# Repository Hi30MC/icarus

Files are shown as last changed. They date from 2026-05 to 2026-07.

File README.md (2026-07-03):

# icarus
Files pertaining to the development of my personal custom keyboard Icarus.

# Ergogen
The keyboard and pcb layout were generated using Ergogen locally. The config files and corresponding outputs can be found in the `ergogen` folder. There are custom footprints that generate 3d models on the footprints of all components, and these are found in `final_pcbs/components`. **The path for these are custom to my file setup, and thus will most likely not work on your machine. Please change the corresponding file paths if you wish to locally build this model.**

# KiCad
The corresponding PCB outputs from Ergogen were traced in KiCad. The final traced PCBs, along with exported STEP files are found in the `final_pcbs` folder. Currently, **the final PCBs do not have the switch and keycap models on the footprints of the switches, and there are traces which have been shown to be on fragile board sections.** Both of these changes will be updated in the near future and this notice will be removed once that happens.

# Case files
The case files were constructed in Onshape. One can view these files [here](https://cad.onshape.com/documents/795d5125a76cdfb5a48cf88b/w/a7573c951f90309017d525a7/e/47b874ca74b5b2133d47f936). There are also STEP files in this repo, in the `case_files` folder. Note that the case files provided are for the left side of the keyboard only, and the right side is simply a mirror image of the left side.

## Travel case files

As of 01 July '26, there are travel case files in the works. Please stay tuned for their release. 

# ZMK configuration.

Icarus currently runs ZMK. The configuration repository and current firmware can be found [here](https://github.com/Hi30MC/zmk-config).

# Physical build notes

This case was designed and printed for FDM, though the battery cage is a major flaw in the design. There are supports that are best printed as "normal slim" supports on Orca, for example, as these had the cleanest release. I found that it was best to print the ports/switches/etc on the case as-is, then clean up with a file, though one may find success with adding supports and removing those manually. Additionally, I reccomend placing brim ears on all corners of the faceplate/skirt print, as well as the baseplate as they tend to warp during printing. Mounting the baseplate to the PCB was done with M2.5 self-threading screws, which need washers to secure onto the board. **Print these separately, and not attached to the baseplate.** There is also a known issue with the right PCB's battery jack hitting against the Kailh hotswap bracket, which will be fixed soon™. Finally, to ensure that the keys fit into the shield, one must use flush cutters on the key-side of the shield to cut the soldering joints flush. It doesn't need to be perfectly flush, but as flush as possible is best. If any other issues arise in whoever decides to build this, please reach out!

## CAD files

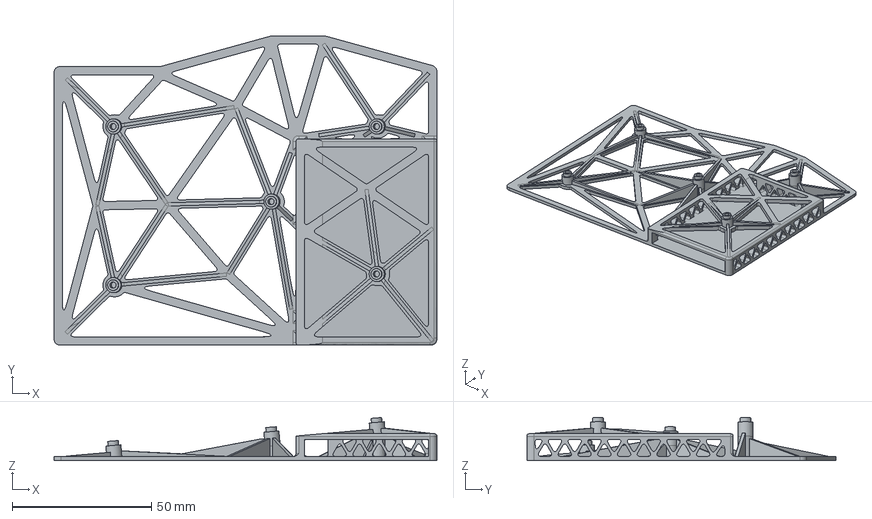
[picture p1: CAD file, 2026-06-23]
case_files/battery_cage_final.step
137.6 x 111.2 x 15.5 mm

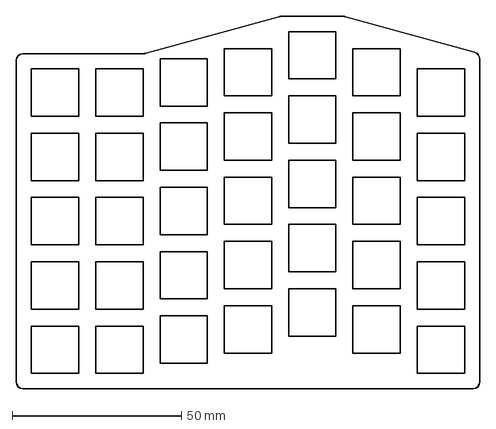
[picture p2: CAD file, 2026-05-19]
ergogen/output/outlines/leftcutout.dxf
137.0 x 110.0 mm

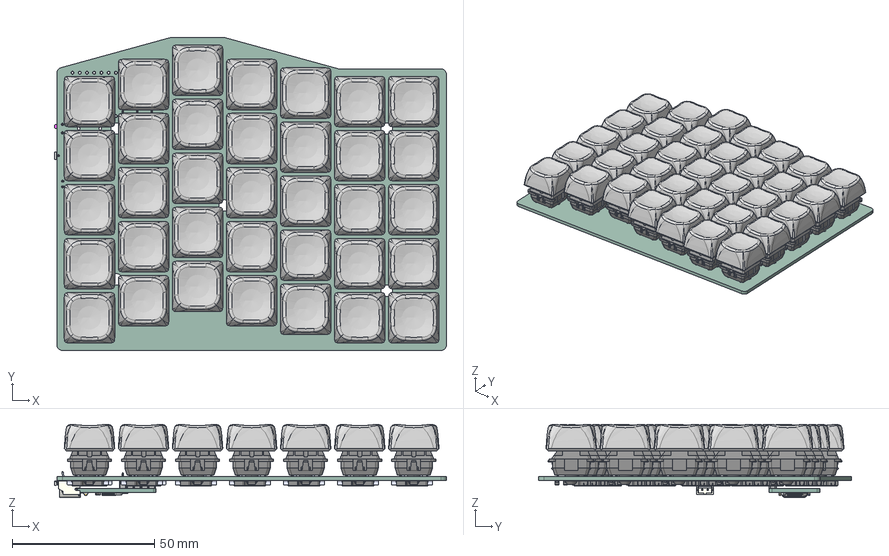
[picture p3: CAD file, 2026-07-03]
final_pcbs/3d/right_pcb.step
137.8 x 110.0 x 25.7 mm
SSSS811101
MMSZ5226B-7-F x 35
PG151101S11 x 35
MX1A-11NN x 35
1.00u (Concave) x 35
nice!nano v1.0
USB_C_Receptacle_16P_TopMnt_Horizontal_GCT_USB4105-xx-A
USB_C_Receptacle_16P_TopMnt_Horizontal_GCT_USB4105-xx-A001
USB_C_Receptacle_16P_TopMnt_Horizontal_GCT_USB4105-xx-A002
USB_C_Receptacle_16P_TopMnt_Horizontal_GCT_USB4105-xx-A003
USB_C_Receptacle_16P_TopMnt_Horizontal_GCT_USB4105-xx-A004
USB_C_Receptacle_16P_TopMnt_Horizontal_GCT_USB4105-xx-A005
USB_C_Receptacle_16P_TopMnt_Horizontal_GCT_USB4105-xx-A006
USB_C_Receptacle_16P_TopMnt_Horizontal_GCT_USB4105-xx-A007
USB_C_Receptacle_16P_TopMnt_Horizontal_GCT_USB4105-xx-A008
USB_C_Receptacle_16P_TopMnt_Horizontal_GCT_USB4105-xx-A009
USB_C_Receptacle_16P_TopMnt_Horizontal_GCT_USB4105-xx-A010
USB_C_Receptacle_16P_TopMnt_Horizontal_GCT_USB4105-xx-A011
USB_C_Receptacle_16P_TopMnt_Horizontal_GCT_USB4105-xx-A012
USB_C_Receptacle_16P_TopMnt_Horizontal_GCT_USB4105-xx-A013
USB_C_Receptacle_16P_TopMnt_Horizontal_GCT_USB4105-xx-A014
USB_C_Receptacle_16P_TopMnt_Horizontal_GCT_USB4105-xx-A015
USB_C_Receptacle_16P_TopMnt_Horizontal_GCT_USB4105-xx-A016
USB_C_Receptacle_16P_TopMnt_Horizontal_GCT_USB4105-xx-A017
USB_C_Receptacle_16P_TopMnt_Horizontal_GCT_USB4105-xx-A018
USB_C_Receptacle_16P_TopMnt_Horizontal_GCT_USB4105-xx-A019
USB_C_Receptacle_16P_TopMnt_Horizontal_GCT_USB4105-xx-A020
USB_C_Receptacle_16P_TopMnt_Horizontal_GCT_USB4105-xx-A021
USB_C_Receptacle_16P_TopMnt_Horizontal_GCT_USB4105-xx-A022
USB_C_Receptacle_16P_TopMnt_Horizontal_GCT_USB4105-xx-A023
USB_C_Receptacle_16P_TopMnt_Horizontal_GCT_USB4105-xx-A024
USB_C_Receptacle_16P_TopMnt_Horizontal_GCT_USB4105-xx-A025
USB_C_Receptacle_16P_TopMnt_Horizontal_GCT_USB4105-xx-A026
USB_C_Receptacle_16P_TopMnt_Horizontal_GCT_USB4105-xx-A027
USB_C_Receptacle_16P_TopMnt_Horizontal_GCT_USB4105-xx-A028
USB_C_Receptacle_16P_TopMnt_Horizontal_GCT_USB4105-xx-A029
USB_C_Receptacle_16P_TopMnt_Horizontal_GCT_USB4105-xx-A030
USB_C_Receptacle_16P_TopMnt_Horizontal_GCT_USB4105-xx-A031
USB_C_Receptacle_16P_TopMnt_Horizontal_GCT_USB4105-xx-A032
USB_C_Receptacle_16P_TopMnt_Horizontal_GCT_USB4105-xx-A033
USB_C_Receptacle_16P_TopMnt_Horizontal_GCT_USB4105-xx-A034
USB_C_Receptacle_16P_TopMnt_Horizontal_GCT_USB4105-xx-A035
Pin9
Pin10
Pin12
Pin11
Pin13
Pin14
Pin15
Pin16
Pin8
Pin7
Pin6
Pin5
Pin4
Pin3
Pin2
Pin1
LED_0603_1608Metric_ON v1
Capacitor v1 x 2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

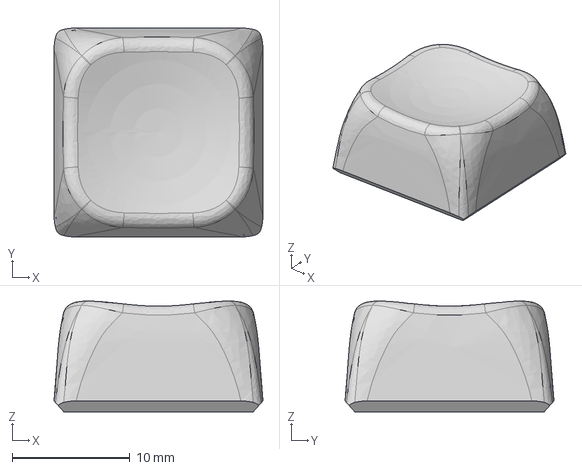
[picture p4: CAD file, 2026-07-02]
final_pcbs/components/moa_cap.step
17.8 x 17.8 x 9.43 mm

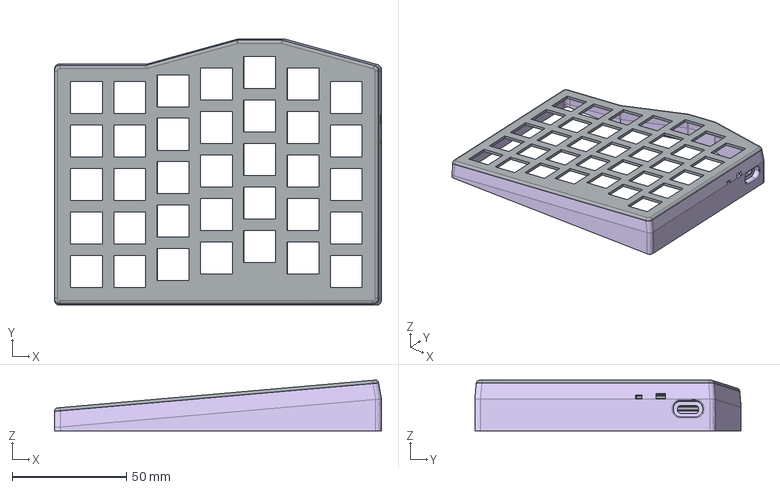
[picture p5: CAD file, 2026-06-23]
case_files/skirt_final.step
142.9 x 116.5 x 22.2 mm
faceplate
skirt

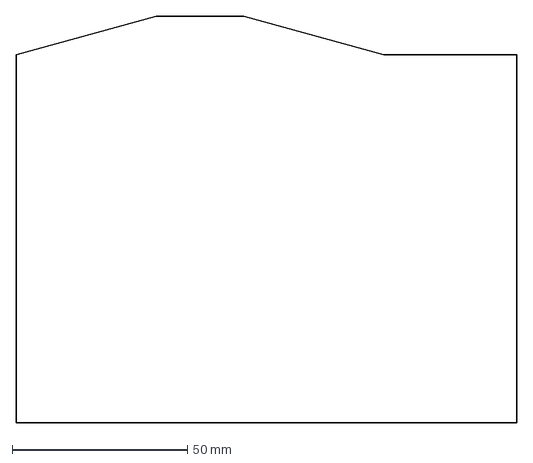
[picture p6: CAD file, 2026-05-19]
ergogen/output/outlines/rightcase.dxf
143.0 x 116.0 mm

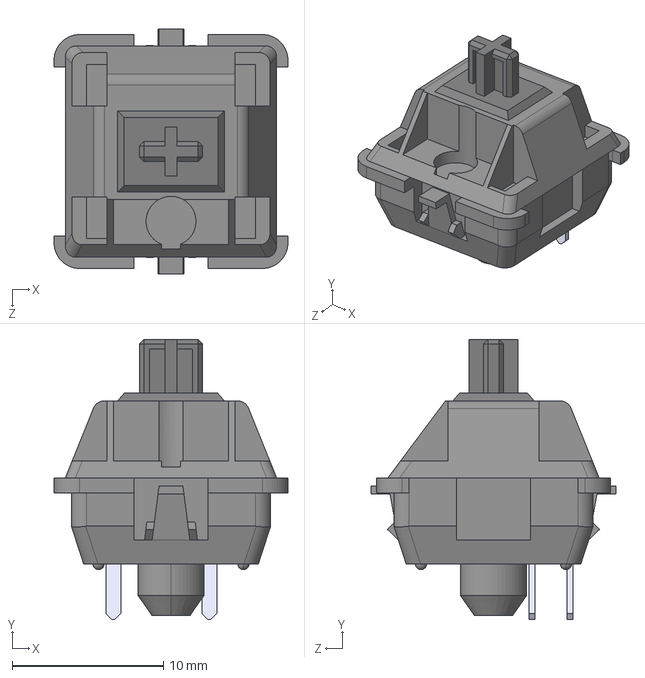
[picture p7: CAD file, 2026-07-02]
final_pcbs/components/MX1A-11NN--3DModel-STEP-510211.STEP
15.5 x 18.5 x 16.2 mm

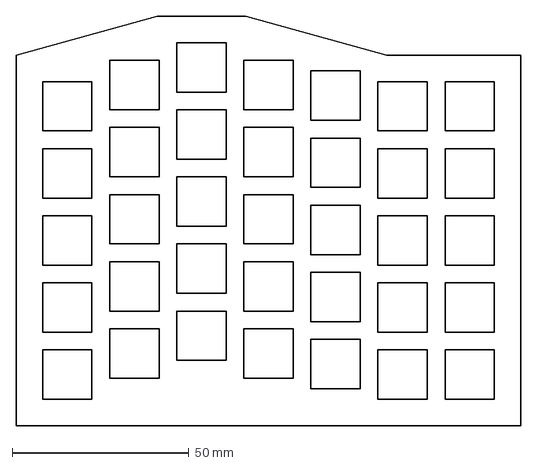
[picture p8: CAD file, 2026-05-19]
ergogen/output/outlines/rightcasecutout.dxf
143.0 x 116.0 mm

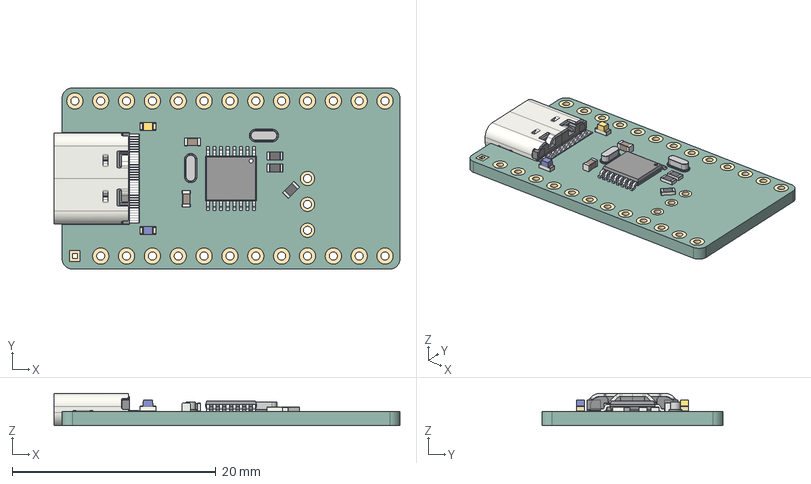
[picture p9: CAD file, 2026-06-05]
final_pcbs/components/nicenano-v2.step
34.0 x 17.8 x 3.16 mm
nice!nano v1.0_1
USB_C_Receptacle_16P_TopMnt_Horizontal_GCT_USB4105-xx-A
USB_C_Receptacle_16P_TopMnt_Horizontal_GCT_USB4105-xx-A001
USB_C_Receptacle_16P_TopMnt_Horizontal_GCT_USB4105-xx-A002
USB_C_Receptacle_16P_TopMnt_Horizontal_GCT_USB4105-xx-A003
USB_C_Receptacle_16P_TopMnt_Horizontal_GCT_USB4105-xx-A004
USB_C_Receptacle_16P_TopMnt_Horizontal_GCT_USB4105-xx-A005
USB_C_Receptacle_16P_TopMnt_Horizontal_GCT_USB4105-xx-A006
USB_C_Receptacle_16P_TopMnt_Horizontal_GCT_USB4105-xx-A007
USB_C_Receptacle_16P_TopMnt_Horizontal_GCT_USB4105-xx-A008
USB_C_Receptacle_16P_TopMnt_Horizontal_GCT_USB4105-xx-A009
USB_C_Receptacle_16P_TopMnt_Horizontal_GCT_USB4105-xx-A010
USB_C_Receptacle_16P_TopMnt_Horizontal_GCT_USB4105-xx-A011
USB_C_Receptacle_16P_TopMnt_Horizontal_GCT_USB4105-xx-A012
USB_C_Receptacle_16P_TopMnt_Horizontal_GCT_USB4105-xx-A013
USB_C_Receptacle_16P_TopMnt_Horizontal_GCT_USB4105-xx-A014
USB_C_Receptacle_16P_TopMnt_Horizontal_GCT_USB4105-xx-A015
USB_C_Receptacle_16P_TopMnt_Horizontal_GCT_USB4105-xx-A016
USB_C_Receptacle_16P_TopMnt_Horizontal_GCT_USB4105-xx-A017
USB_C_Receptacle_16P_TopMnt_Horizontal_GCT_USB4105-xx-A018
USB_C_Receptacle_16P_TopMnt_Horizontal_GCT_USB4105-xx-A019
USB_C_Receptacle_16P_TopMnt_Horizontal_GCT_USB4105-xx-A020
USB_C_Receptacle_16P_TopMnt_Horizontal_GCT_USB4105-xx-A021
USB_C_Receptacle_16P_TopMnt_Horizontal_GCT_USB4105-xx-A022
USB_C_Receptacle_16P_TopMnt_Horizontal_GCT_USB4105-xx-A023
USB_C_Receptacle_16P_TopMnt_Horizontal_GCT_USB4105-xx-A024
USB_C_Receptacle_16P_TopMnt_Horizontal_GCT_USB4105-xx-A025
USB_C_Receptacle_16P_TopMnt_Horizontal_GCT_USB4105-xx-A026
USB_C_Receptacle_16P_TopMnt_Horizontal_GCT_USB4105-xx-A027
USB_C_Receptacle_16P_TopMnt_Horizontal_GCT_USB4105-xx-A028
USB_C_Receptacle_16P_TopMnt_Horizontal_GCT_USB4105-xx-A029
USB_C_Receptacle_16P_TopMnt_Horizontal_GCT_USB4105-xx-A030
USB_C_Receptacle_16P_TopMnt_Horizontal_GCT_USB4105-xx-A031
USB_C_Receptacle_16P_TopMnt_Horizontal_GCT_USB4105-xx-A032
USB_C_Receptacle_16P_TopMnt_Horizontal_GCT_USB4105-xx-A033
USB_C_Receptacle_16P_TopMnt_Horizontal_GCT_USB4105-xx-A034
USB_C_Receptacle_16P_TopMnt_Horizontal_GCT_USB4105-xx-A035
Pin9
Pin10
Pin12
Pin11
Pin13
Pin14
Pin15
Pin16
Pin8
Pin7
Pin6
Pin5
Pin4
Pin3
Pin2
Pin1
LED_0603_1608Metric_ON
C_0603_1608Metric x 2
LED_0603_1608Metric_ON_1
Crystal Oscillator x 2
R_0603_1608Metric x 4

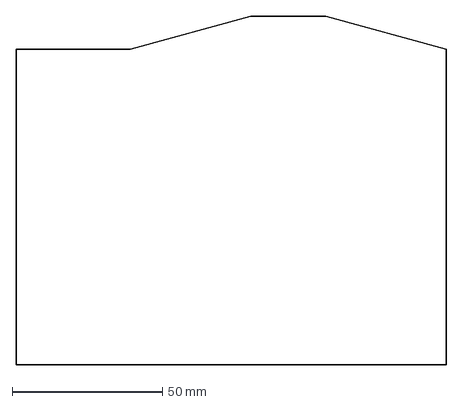
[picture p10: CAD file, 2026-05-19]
ergogen/output/outlines/leftcase.dxf
143.0 x 116.0 mm

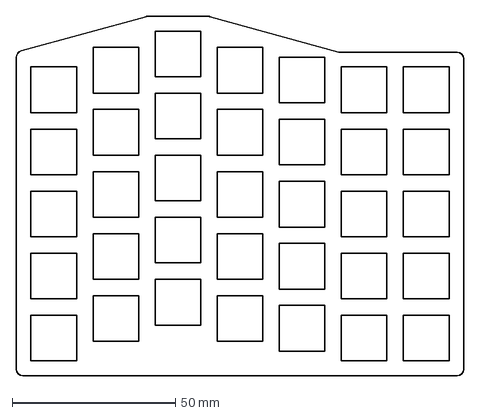
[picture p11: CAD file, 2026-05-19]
ergogen/output/outlines/rightcutout.dxf
137.0 x 110.0 mm

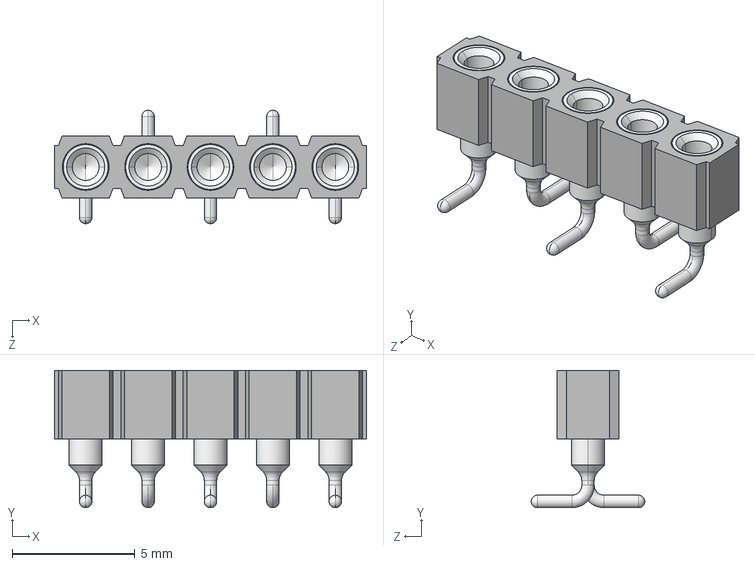
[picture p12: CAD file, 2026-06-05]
final_pcbs/components/310-43-105-41-105000.stp
12.7 x 5.59 x 4.62 mm
P3XX-11-010-00-000000_P305-11-010-00-000000

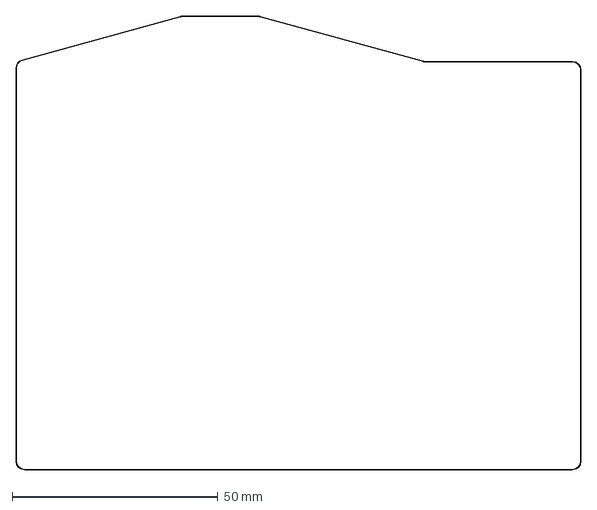
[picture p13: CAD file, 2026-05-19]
ergogen/output/outlines/rightboard.dxf
137.0 x 110.0 mm

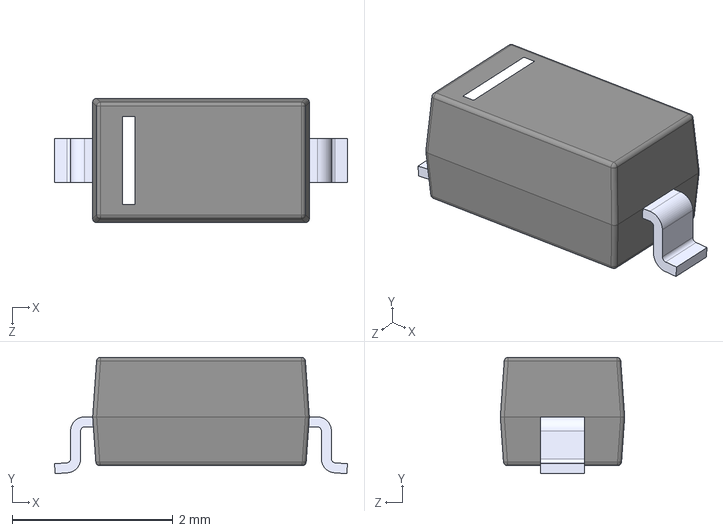
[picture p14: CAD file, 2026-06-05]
final_pcbs/components/1N4148W-13-F.STEP
3.65 x 1.45 x 1.55 mm

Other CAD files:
final_pcbs/3d/left_pcb.step
ergogen/output/outlines/leftcasecutout.dxf
final_pcbs/components/SSSS811101.STEP
ergogen/output/outlines/keys.dxf
ergogen/output/outlines/leftboard.dxf
final_pcbs/components/EVQPUL02K.stp
final_pcbs/components/PG151101S11--3DModel-STEP-1.STEP
final_pcbs/components/S2B-PH-K-S(LF)(SN).STEP

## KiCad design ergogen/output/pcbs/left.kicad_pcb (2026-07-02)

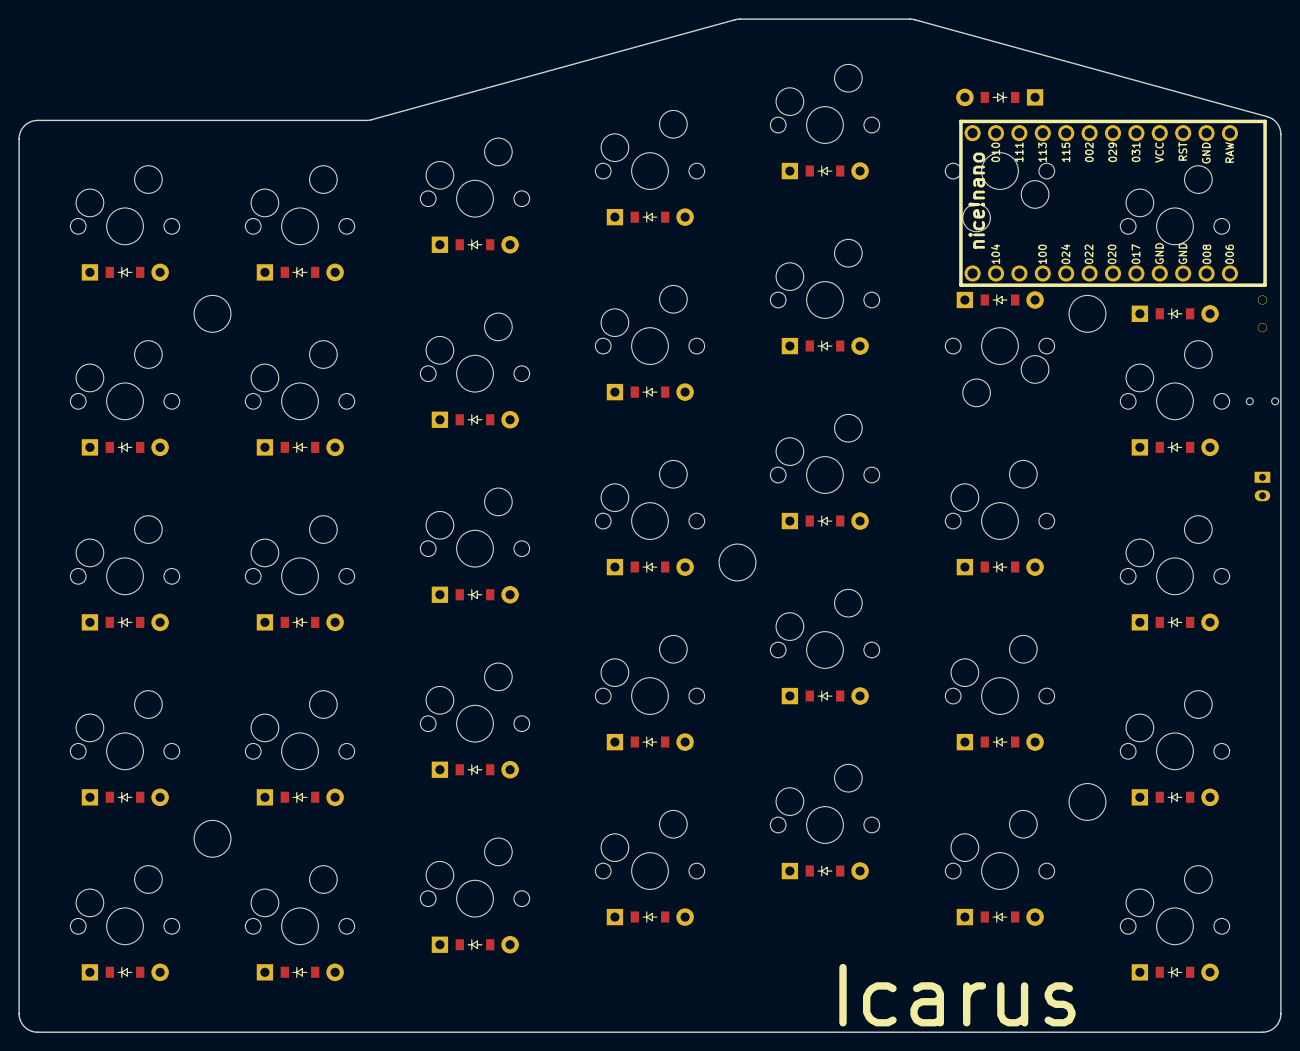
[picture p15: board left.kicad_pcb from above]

Board: 2 copper layers, 137.0 x 110.0 mm, 74 parts (0 on the bottom side), 51 nets, no tracks yet.

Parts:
B1: Panasonic_EVQPUL_EVQPUC
D1, D2, D3, D4, D5, D6, D7, D8, D9, D10, D11, D12, D13, D14, D15, D16, D17, D18, D19, D20, D21, D22, D23, D24, D25, D26, D27, D28, D29, D30, D31, D32, D33, D34, D35: ComboDiode
JST1: JST_PH_S2B-PH-K_02x2.00mm_Angled
MCU1: nice_nano
S1, S2, S3, S4, S5, S6, S7, S8, S9, S10, S11, S12, S13, S14, S15, S16, S17, S18, S19, S20, S21, S22, S23, S24, S25, S26, S27, S28, S29, S30, S31, S32, S33, S34, S35: MX
T1: SPDT_C128955

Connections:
GND: B1.1, JST1.2, MCU1.3, MCU1.4, MCU1.23
P002: MCU1.18, S1.1, S2.1, S3.1, S4.1, S5.1
P009: MCU1.13, S26.1, S27.1, S28.1, S34.1, S35.1
P010: MCU1.14, S21.1, S22.1, S23.1, S24.1, S25.1
P017: D5.1, D10.1, D15.1, D20.1, D25.1, D34.1, D35.1, MCU1.5
P020: D1.1, D6.1, D11.1, D16.1, D21.1, D26.1, D29.1, MCU1.6
P022: D2.1, D7.1, D12.1, D17.1, D22.1, D27.1, D30.1, MCU1.7
P024: D3.1, D8.1, D13.1, D18.1, D23.1, D28.1, D31.1, MCU1.8
P031: MCU1.20, S29.1, S30.1, S31.1, S32.1, S33.1
P100: D4.1, D9.1, D14.1, D19.1, D24.1, D32.1, D33.1, MCU1.9
P111: MCU1.15, S16.1, S17.1, S18.1, S19.1, S20.1
P113: MCU1.16, S11.1, S12.1, S13.1, S14.1, S15.1
P115: MCU1.17, S6.1, S7.1, S8.1, S9.1, S10.1
RAW: MCU1.24, T1.2
RST: B1.2, MCU1.22
index_bottom: D27.2, S27.2
index_home: D28.2, S28.2
index_num: D34.2, S35.2
index_space: D26.2, S26.2
index_top: D33.2, S34.2
inner_bottom: D30.2, S30.2
inner_home: D31.2, S31.2
inner_num: D35.2, S33.2
inner_space: D29.2, S29.2
inner_top: D32.2, S32.2
macro_bottom: D2.2, S2.2
macro_home: D3.2, S3.2
macro_num: D5.2, S5.2
macro_space: D1.2, S1.2
macro_top: D4.2, S4.2
middle_bottom: D22.2, S22.2
middle_home: D23.2, S23.2
middle_num: D25.2, S25.2
middle_space: D21.2, S21.2
middle_top: D24.2, S24.2
outer_bottom: D7.2, S7.2
outer_home: D8.2, S8.2
outer_num: D10.2, S10.2
outer_space: D6.2, S6.2
outer_top: D9.2, S9.2
pinky_bottom: D12.2, S12.2
pinky_home: D13.2, S13.2
pinky_num: D15.2, S15.2
pinky_space: D11.2, S11.2
pinky_top: D14.2, S14.2
pos: JST1.1, T1.1
ring_bottom: D17.2, S17.2
ring_home: D18.2, S18.2
ring_num: D20.2, S20.2
ring_space: D16.2, S16.2
ring_top: D19.2, S19.2

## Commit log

2026-04-29 base commit with some test files
    [keyboard_left.3mf, left.dxf, left.kicad_pcb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]
2026-04-29 TO-DO: aux bits on the PCB (battery, reset, and on/off)
    [left.kicad_pcb, left_pcb.dxf, leftcutout.dxf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]
2026-04-29 right board
    [left.kicad_pcb, leftboard.dxf, leftframe.dxf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]
2026-04-30 basically done pcbs
    [frame.dxf, keys.dxf, left.kicad_pcb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]
2026-04-30 pcbs without images
    [left_final.kicad_pcb, right_final.kicad_pcb]
2026-05-19 redesign for short board, left but no right pcb. Final pcbs for old design
    [frame.dxf, keys.dxf, left.kicad_pcb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]
2026-05-19 restructured file system; final short pcbs. Old PCBs are trashed and other cleaning.
    [keys.dxf, left.kicad_pcb, leftboard.dxf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]
2026-06-05 regenned with board flipped correctly; traced pcbs to be redone
    [left.kicad_pcb, right.kicad_pcb]
2026-06-05 reorganised files, board retrace todo
    [1N4148W-13-F.STEP, 310-43-105-41-105000.stp, EVQPUL02K.stp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]
2026-06-05 regen board with custom footprints to have 3d models autogenned
    [left.kicad_pcb, left_final_short.kicad_pcb, left_pcb.step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]
2026-06-09 all board retraced and finalised; ordered.
    [left_final.kicad_pcb, left_final_short.kicad_pcb, right_final.kicad_pcb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]
2026-06-10 change README, add .step for right_pcb
    [left_final_short.kicad_pcb, right_final_short.kicad_pcb, right_pcb.step]
2026-06-23 final case files
    [battery_cage_final.step, skirt_final.step]
2026-07-02 add switches and caps to ergogen output; not final pcb
    [MX1A-11NN--3DModel-STEP-510211.STEP, left.kicad_pcb, moa_cap.step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]
2026-07-03 README update; new models
    [left_pcb.step, right_pcb.step]
